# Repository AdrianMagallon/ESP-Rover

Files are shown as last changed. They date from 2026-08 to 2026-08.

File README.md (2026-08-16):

## WiFi Robot Car

A browser-controlled robot car built on an ESP32. It creates its own WiFi access point, hosts a little web interface, and lets you drive it around using an on-screen directional pad — no internet connection required.

## Background

This was built as part of the **Google Code Next** program, which introduced me to robotics for the first time. Going in, I had basically no experience with robotics and not much with C++ either. It was a lot to take in at first — figuring out hardware, motor control, and a new language all at once was pretty overwhelming. But over the course of the program it started clicking, and by the end I was a lot more comfortable with C++ than I expected to be. This project is the result of that whole journey, and it's something I'm genuinely proud of.

## How It Works

When the ESP32 boots up, it spins up a WiFi access point (default SSID: `robot`, password: `12345678`) and starts a basic HTTP server on port 80. You connect your phone or laptop to that network, open a browser, and navigate to the ESP32's IP address (printed to Serial on startup — usually `192.168.4.1`).

The web page shows a 3x3 grid of direction buttons: forward, backward, left, right, and four diagonals, plus a stop button in the middle. Pressing a button sends an HTTP POST request to a matching endpoint (like `/forward` or `/leftBackward`). The ESP32 reads that request and calls `drive()`, a throttle/steering mixer that computes matching left/right motor speeds — see `MotorControl.cpp`.

## Hardware

The build uses an ESP32 development board, 2 TT gear DC motors (the yellow ones, one per driven wheel — left and right), an L298N H-bridge motor driver, an LM2596 buck converter (steps the battery voltage down to 3.3V for the ESP32), a battery pack (the original single 9V battery is fine for 2 motors), and a front-mounted ball caster in place of a third and fourth wheel — it's a passive wheel with no motor, so it just bolts on and needs no wiring. The firmware also supports an optional 4WD layout (no caster, four driven motors) if you'd rather build that instead; see MOTORS_PER_SIDE below.

### Wiring

The battery splits two ways: straight into the L298N board(s) to drive the motors, and into the buck converter which steps it down to 3.3V for the ESP32.

`MotorControl.h` defines `MOTORS_PER_SIDE`, set to `1` for this two-wheel-drive-plus-caster build (one motor per side), and `MotorControl.cpp` lists the actual pin numbers for every motor. The single-L298N wiring is:

| L298N Signal | ESP32 Pin |
|---|---|
| ENA (PWM) | 12 |
| IN1 | 14 |
| IN2 | 27 |
| IN3 | 26 |
| IN4 | 25 |
| ENB (PWM) | 33 |

The ball caster needs no wiring at all — it's a passive wheel with no motor, so it just bolts onto the front of the chassis. Mount it roughly matched to the driven wheel height so the chassis sits level, and centered under the battery pack's weight for stability. If you'd rather build the optional 4WD layout instead, set `MOTORS_PER_SIDE` to `2` and wire a second L298N to the rear-motor pins in `MotorControl.cpp` (update the placeholder pins there to match your wiring). Avoid GPIO12 if you run into boot problems, since it's one of the ESP32's boot "strapping" pins.

Motor speed is set to 225/255 by default. Diagonal movements slow down one side to produce a turning arc; `drive()` handles the actual mixing so this works the same whether a side has one motor or two.

## Schematic

A full KiCad schematic for the wiring described above is included in this repo under [`Hardware/`](./Hardware), along with an exported [`Schematic.pdf`](./Hardware/Schematic.pdf) for quick viewing without needing KiCad installed. Open the `.kicad_pro` file in KiCad if you want to view or edit the schematic directly.

## File Structure

```
Robot-main.ino # Main sketch — WiFi setup, HTTP server loop, request routing
MotorControl.cpp/h # Motor pin setup, the drive() throttle/steering mixer, and movement functions
WiFiSetup.cpp/h # Starts the ESP32 as a WiFi access point (SoftAP)
HtmlResponse.cpp/h # Serves the control UI as an HTTP response
```

## Setup & Flashing

Open the project in the Arduino IDE (or PlatformIO) and make sure the ESP32 board package is installed. If you want, change the WiFi credentials at the top of `Robot-main.ino`:

```cpp
const char *ssid = "robot";
const char *password = "12345678";
```

Then select your ESP32 board and the correct COM port, flash it, and open Serial Monitor at **115200 baud** to see the AP IP address after boot.

## Connecting & Driving

Connect your device to the `robot` WiFi network, then open a browser and go to `http://192.168.4.1` (confirm the IP in Serial Monitor if it's different). The control pad should load immediately, and it works on mobile too since the buttons respond to touch events.

## Known Issues / Things to Fix

Touch release now correctly sends `/stop`. An earlier bug had it calling `toggleCheckbox('stop')`, a function that was never defined, so lifting your finger did nothing on mobile; that's been fixed.

The WiFi credentials are hardcoded, so definitely change the password before using this around other people.

The HTTP server handles one client at a time and closes the connection after each request, so there's a small delay between commands. Holding a direction button now sends continuous input: the browser resends that command every 150ms for as long as the button stays pressed, and releasing it sends `/stop` — see the script in `HtmlResponse.cpp`.

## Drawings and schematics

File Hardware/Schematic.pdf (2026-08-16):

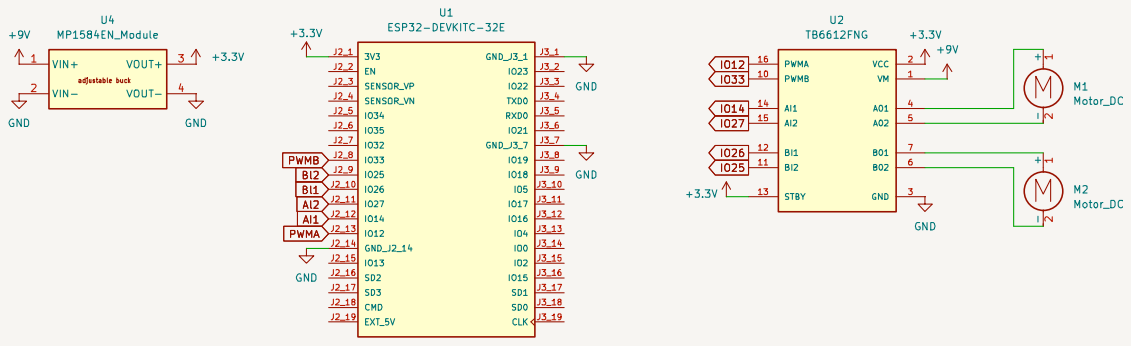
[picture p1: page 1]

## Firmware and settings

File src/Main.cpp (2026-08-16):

#include <WiFi.h>
#include "MotorControl.h"
#include "HtmlResponse.h"
#include "WiFiSetup.h"
#include <Arduino.h>

// WiFi credentials for the robot's access point.
// Change these before deploying — especially the password.
const char *ssid = "robot";
const char *password = "12345678";
// How long (ms) to wait for more data before dropping a client connection.
const unsigned long CLIENT_TIMEOUT_MS = 5000;

WiFiServer server(80);

void setup()
{
    pinMode(LED_BUILTIN, OUTPUT);
    Serial.begin(115200);

    setupMotorPins();
    setupWiFi(ssid, password);

    IPAddress myIP = WiFi.softAPIP();
    Serial.print("AP IP address: ");
    Serial.println(myIP);

    server.begin();
    Serial.println("Server started");
}

void loop()
{
    WiFiClient client = server.available();

    if (client)
    {
        Serial.println("New Client.");
        String currentLine = "";
        unsigned long timeout = millis();

        while (client.connected() && millis() - timeout < CLIENT_TIMEOUT_MS)
        {
            if (client.available())
            {
                char c = client.read();
                timeout = millis(); // Reset timeout on each received byte
                Serial.write(c);

                if (c == '\n')
                {
                    if (currentLine.length() == 0)
                    {
                        // Blank line = end of HTTP headers; send the control page
                        sendHtmlResponse(client);
                        break;
                    }
                    else
                    {
                        currentLine = "";
                    }
                }
                else if (c != '\r')
                {
                    currentLine += c;
                }

                // Route incoming POST requests to motor commands.
                // NOTE: Diagonal/compound routes (e.g. /rightForward) must be checked
                // before their prefix matches (e.g. /right, /forward) to avoid a
                // substring false-match cutting off the more specific route.
                if (currentLine.indexOf("POST /rightForward") >= 0) {
                    rightForward();
                }
                else if (currentLine.indexOf("POST /leftForward") >= 0) {
                    leftForward();
                }
                else if (currentLine.indexOf("POST /rightBackward") >= 0) {
                    rightBackward();
                }
                else if (currentLine.indexOf("POST /leftBackward") >= 0) {
                    leftBackward();
                }
                else if (currentLine.indexOf("POST /forward") >= 0) {
                    forward();
                }
                else if (currentLine.indexOf("POST /backward") >= 0) {
                    backward();
                }
                else if (currentLine.indexOf("POST /right") >= 0) {
                    right();
                }
                else if (currentLine.indexOf("POST /left") >= 0) {
                    left();
                }
                else if (currentLine.indexOf("POST /stop") >= 0) {
                    stopCar();
                }
            }
        }

        // Done with this client — close and log
        client.stop();
        Serial.println("Client Disconnected.");
    }
}

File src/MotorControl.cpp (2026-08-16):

#include <Arduino.h>
#include "MotorControl.h"

// Each motor needs two direction pins (H-bridge IN1/IN2) and one
// PWM-capable enable pin. Motors are grouped by side (left/right)
// because a skid-steer chassis always drives every motor on a side
// identically -- this is what lets the same drive() mixer work for
// 2WD (MOTORS_PER_SIDE = 1) or 4WD (MOTORS_PER_SIDE = 2, front + rear)
// without any other code changes.
//
// The original 2-motor build only needs a single L298N (one channel
// per side), and the pin numbers below for "front" match that original
// wiring. A 4WD build needs a second driver board (or a 4-channel
// driver) wired to the "rear" pins -- update those to match your
// actual wiring.
//
// NOTE: GPIO12 (used below for the front-left enable pin) is an ESP32
// boot "strapping" pin (MTDI). If your board fails to boot with a
// driver wired to it, move that connection to a different
// PWM-capable pin instead.

struct MotorPins {
  uint8_t pin1;
  uint8_t pin2;
  uint8_t enablePin;
};

static MotorPins leftMotors[MOTORS_PER_SIDE] = {
{14, 27, 12}, // Front-left (same pins as the original "motor1")
#if MOTORS_PER_SIDE > 1
{32, 15, 13}, // Rear-left -- update to match your second driver board
#endif
};

static MotorPins rightMotors[MOTORS_PER_SIDE] = {
{26, 25, 33}, // Front-right (same pins as the original "motor2")
#if MOTORS_PER_SIDE > 1
{17, 16, 4}, // Rear-right -- update to match your second driver board
#endif
};

// Default drive speed (0-255). Lower this if the robot moves too fast.
static const int MAX_SPEED = 225;

static void setupSide(MotorPins *motors) {
    for (uint8_t i = 0; i < MOTORS_PER_SIDE; i++) {
    pinMode(motors[i].pin1, OUTPUT);
    pinMode(motors[i].pin2, OUTPUT);
    pinMode(motors[i].enablePin, OUTPUT);
    }
}

// Drives every motor on one side at the same signed speed.
// speed > 0 -> forward, speed < 0 -> reverse, 0 -> coast.
static void setSideSpeed(MotorPins *motors, int speed) {
    bool goForward = speed >= 0;
  int magnitude = speed < 0 ? -speed : speed;
  uint8_t pwm = magnitude > 255 ? 255 : (uint8_t)magnitude;

  for (uint8_t i = 0; i < MOTORS_PER_SIDE; i++) {
    digitalWrite(motors[i].pin1, goForward ? LOW : HIGH);
    digitalWrite(motors[i].pin2, goForward ? HIGH : LOW);
    analogWrite(motors[i].enablePin, pwm);
  }
}

void setupMotorPins() {
    setupSide(leftMotors);
  setupSide(rightMotors);
}

void stopCar() {
    Serial.println("Stop");
  setSideSpeed(leftMotors, 0);
  setSideSpeed(rightMotors, 0);
}

// Tank-style mixer: combines a forward/back throttle with a left/right
// steering value into independent left/right side speeds. Every motor
// on a side is always driven identically, so this same function drives
// 2WD or 4WD chassis without changes.
//   throttle: -255 (full reverse) .. 255 (full forward)
//   steering: -255 (full left) .. 255 (full right)
void drive(int throttle, int steering) {
    if (throttle > 255) throttle = 255;
  if (throttle < -255) throttle = -255;
  if (steering > 255) steering = 255;
  if (steering < -255) steering = -255;

  int leftSpeed = throttle + steering;
  int rightSpeed = throttle - steering;

  if (leftSpeed > 255) leftSpeed = 255;
  if (leftSpeed < -255) leftSpeed = -255;
  if (rightSpeed > 255) rightSpeed = 255;
  if (rightSpeed < -255) rightSpeed = -255;

  setSideSpeed(leftMotors, leftSpeed);
  setSideSpeed(rightMotors, rightSpeed);
}

// Compatibility wrappers for the existing web UI (8 fixed-direction
// buttons). Each one just calls drive() with fixed throttle/steering.
// Note: steering is negated for the two backward diagonals relative to
// their forward counterparts -- this reproduces the original hand-written
// behavior, where "right" diagonals always slowed the right-side motor
// and "left" diagonals always slowed the left-side motor, regardless of
// whether the car was moving forward or backward.

void forward() {
    Serial.println("Forward");
  drive(MAX_SPEED, 0);
}

void backward() {
    Serial.println("Backward");
  drive(-MAX_SPEED, 0);
}

void right() {
    Serial.println("right");
  drive(0, MAX_SPEED);
}

void left() {
    Serial.println("left");
  drive(0, -MAX_SPEED);
}

void rightForward() {
    Serial.println("Right Forward");
  drive(MAX_SPEED, MAX_SPEED / 2);
}

void leftForward() {
    Serial.println("Left Forward");
  drive(MAX_SPEED, -MAX_SPEED / 2);
}

void rightBackward() {
    Serial.println("Right Backward");
  drive(-MAX_SPEED, -MAX_SPEED / 2);
}

void leftBackward() {
    Serial.println("Left Backward");
  drive(-MAX_SPEED, MAX_SPEED / 2);
}

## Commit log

2026-08-16 Add initial project files for ESP32 robot control.
2026-08-16 Initialize README.md with project details
    Added detailed project description, hardware setup, wiring instructions, and known issues for the WiFi Robot Car project.
2026-08-16 Add schematic section to README
    Added a section for the schematic and included links to the KiCad files.
2026-08-16 Update schematic file paths in README
